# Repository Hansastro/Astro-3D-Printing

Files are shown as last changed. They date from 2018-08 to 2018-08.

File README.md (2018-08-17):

# Some 3D Objects to print for Astronomy

Now the 3D printing is become more and more popular. It is possible to create the objects we need.

The models availables are:
- [Polar finder adapter](./Polar_finder_adapter/README.md) for Canon 90° finder.
- [Finder support](./EOS1200D_Finder_Support/README.md) for a EOS 1200D

All models are under Creative Common Licence (BY-NC-SA)



The STL files are accessible per link. If you want the source files to make some modifications, they are available in the repository. You have just to clone it.

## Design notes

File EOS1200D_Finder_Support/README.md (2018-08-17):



# EOS 1200D Finder Support
Taking some photos of the night sky with a reflex camera only is not easy. The finder is two dark and the livevew allow to see only the really bright stars.

With a short focal it is possible to adjust the orientation but when we want to use a longer one, it become hard to find the object we want.

You will find here an adapter to mount a finder on a EOS 1200D.
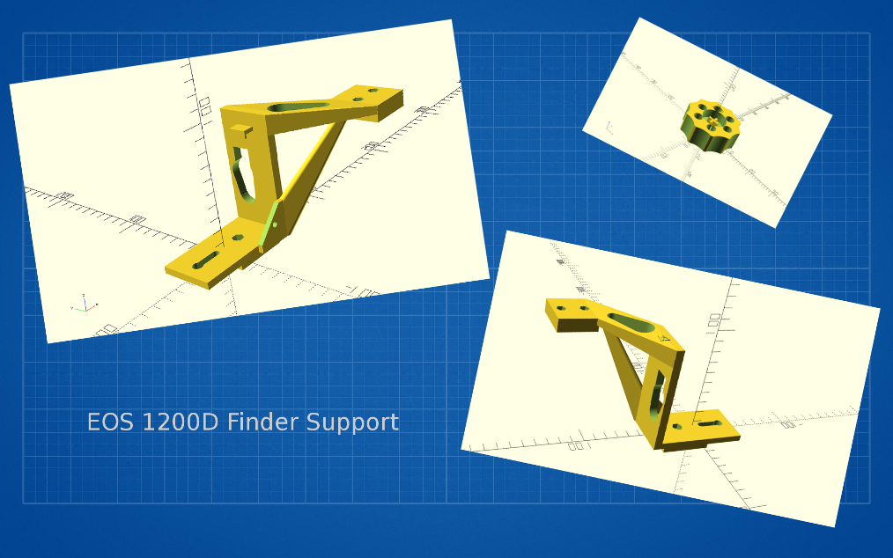
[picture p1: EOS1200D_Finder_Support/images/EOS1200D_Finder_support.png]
EOS1200D Finder support image


Why on the side? 
The finder is placed on the side, because this position is more confortable if we have a 90° finder. With the finder on the flash place, the screen of the camera will be very low. (The EOS 1200 have a fix screen)

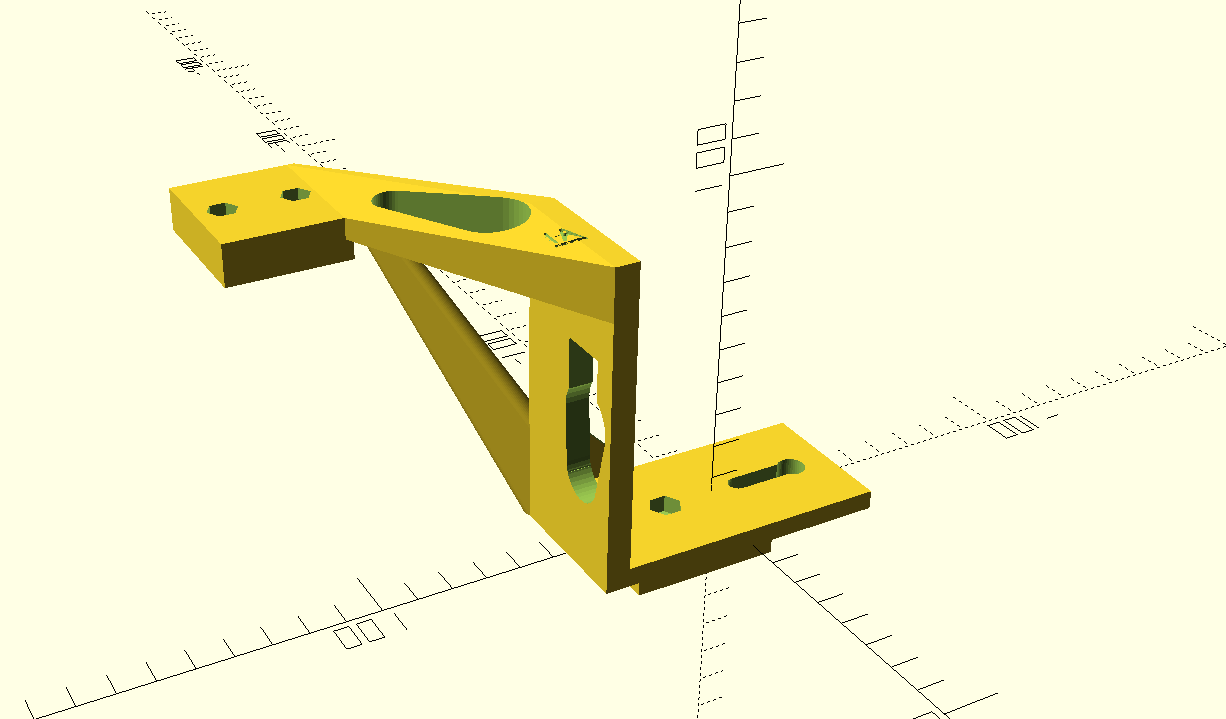
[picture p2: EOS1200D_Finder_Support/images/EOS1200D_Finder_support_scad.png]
EOS1200D Finder support image 1

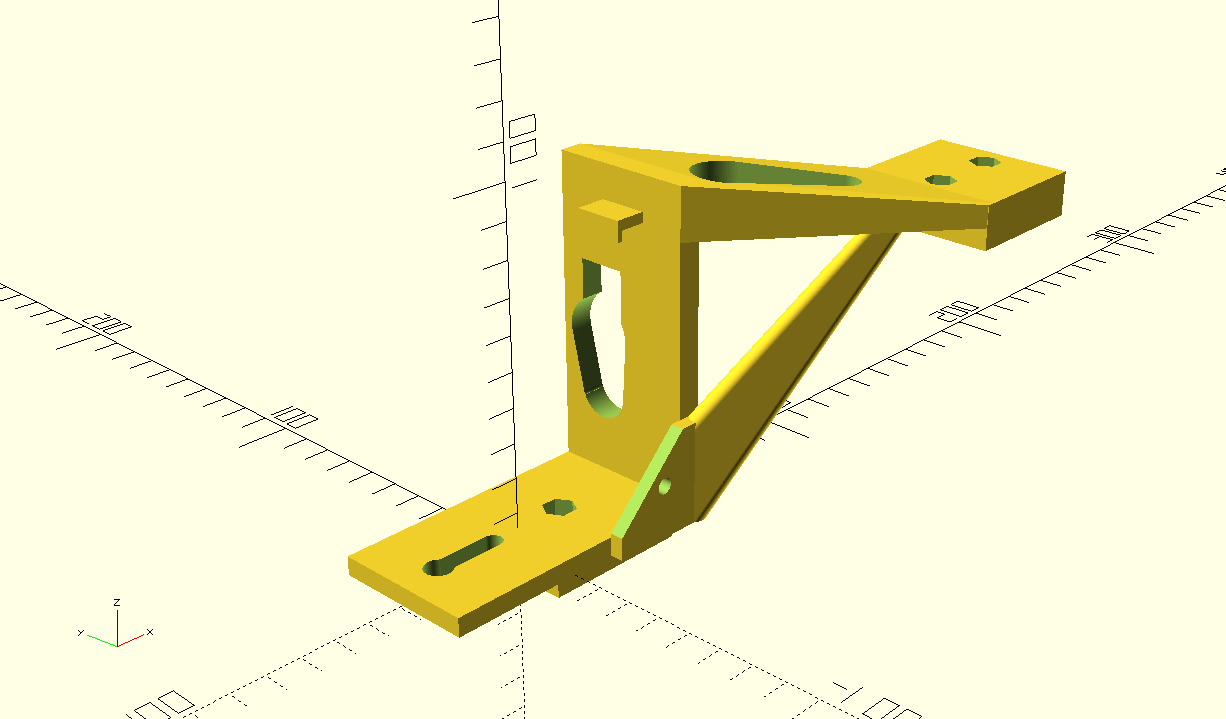
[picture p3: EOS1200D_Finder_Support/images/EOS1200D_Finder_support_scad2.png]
EOS1200D Finder support image 2


The shape is quite complex and to print it some support are required:
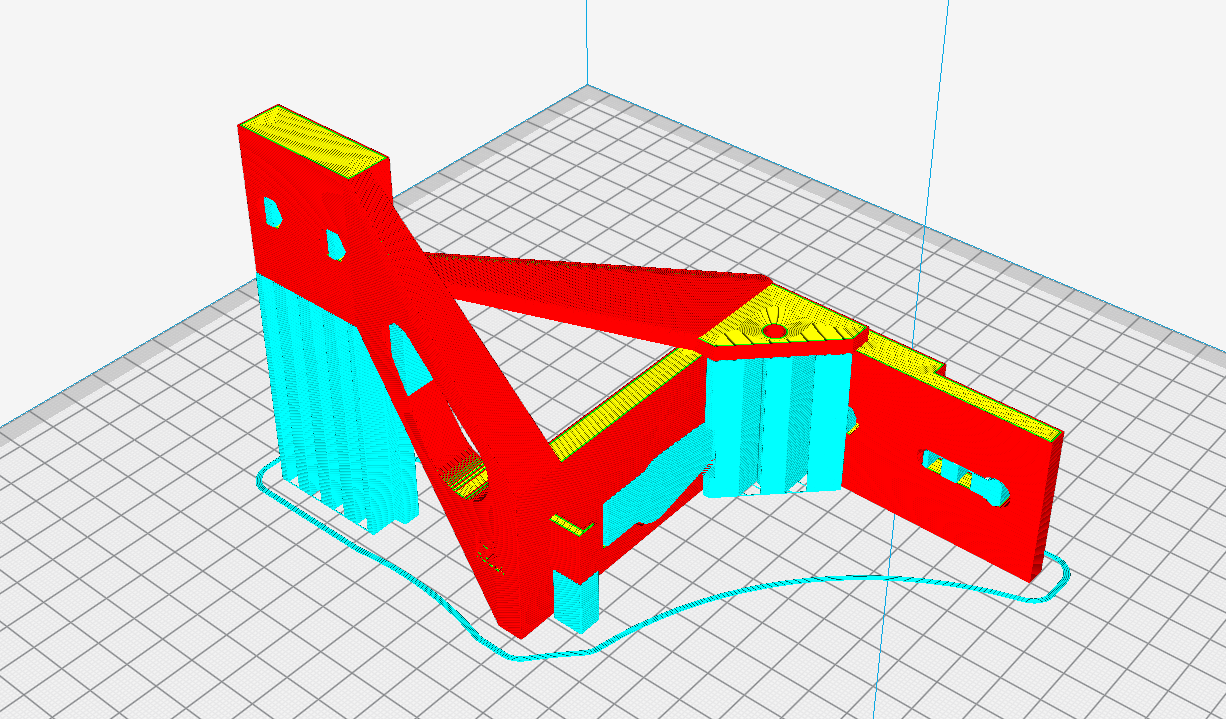
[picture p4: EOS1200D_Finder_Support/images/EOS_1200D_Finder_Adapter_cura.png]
Printing of the support


The STL files are available here:
- [EOS1200D_Finder_Support.stl](EOS1200D_Finder_Support.stl)
- [ScrewHead.stl](ScrewHead.stl) (optional)

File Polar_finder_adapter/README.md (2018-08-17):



# Polar finder adapter

The purpose of this adapter is to mount a canon 90° finder to a polar finder. The ajustement of the mount is very easier, particularly for the people who live quite in north.

Two adapters are provided:
- one for canon 90° finder to a ioptron skytracker polar finder.
- one for canon 90° finder to a Skywatcher EQ6 mount polar finder

The diameter is the same just the length changes.

Those adapters are usable on other polar finder of similar diameter.

The short version (works well for Ioptron skytracker)
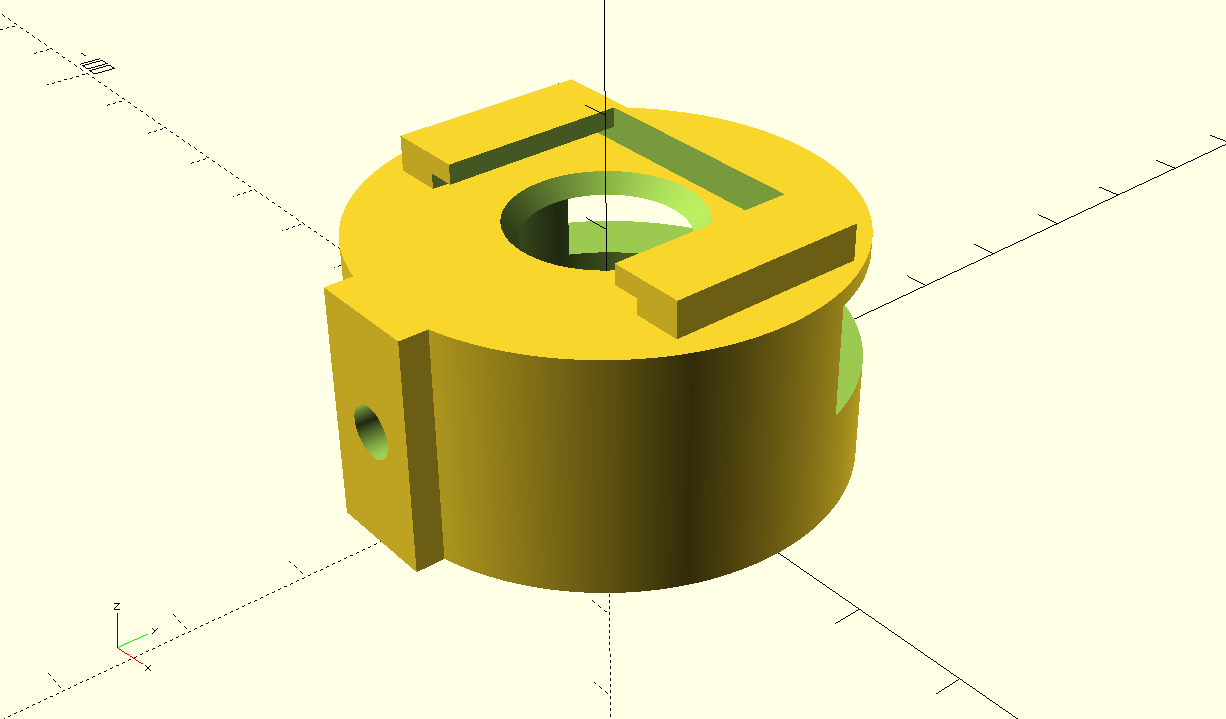
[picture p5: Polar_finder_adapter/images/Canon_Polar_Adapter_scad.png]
Canon adapter short version


The long one (works for Skywatcher EQ6 and all mount with equivalent polar finder)
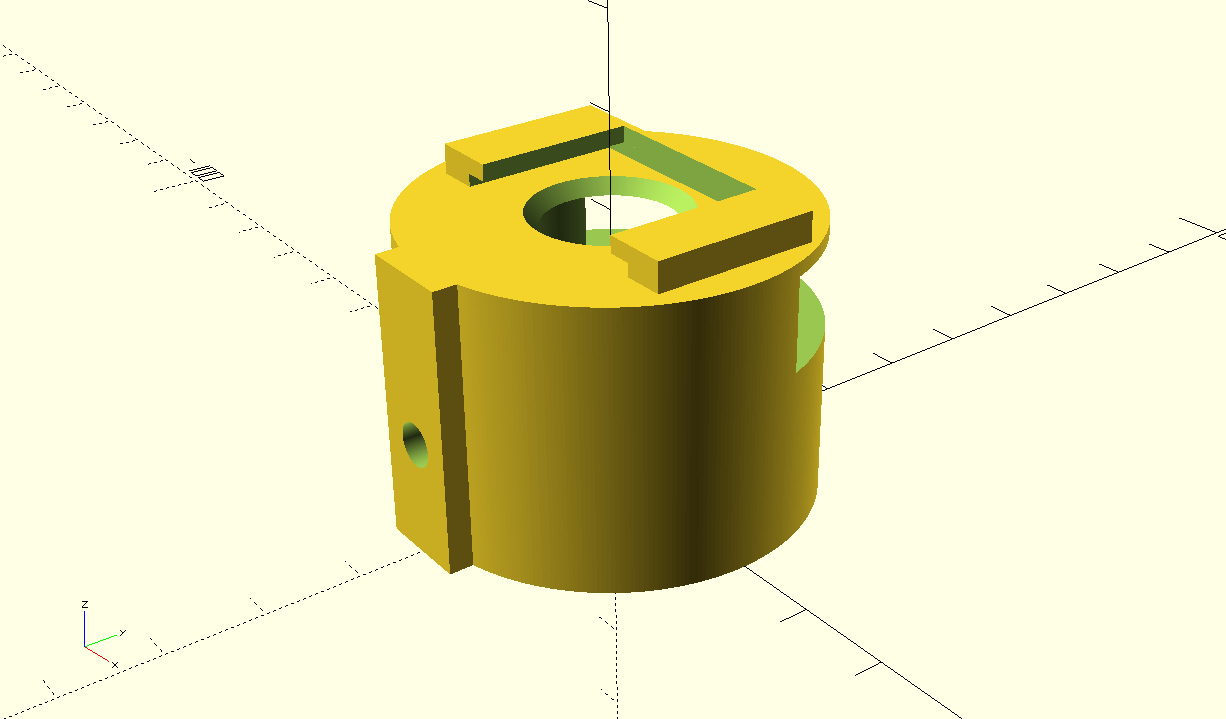
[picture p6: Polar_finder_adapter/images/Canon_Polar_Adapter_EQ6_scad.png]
Canon adapter long version


The srew to secure the adapter on the finder is a M5 in plastic. (You have to thread the hole). For a more confortable usage, a cover for the head of the screw is available:
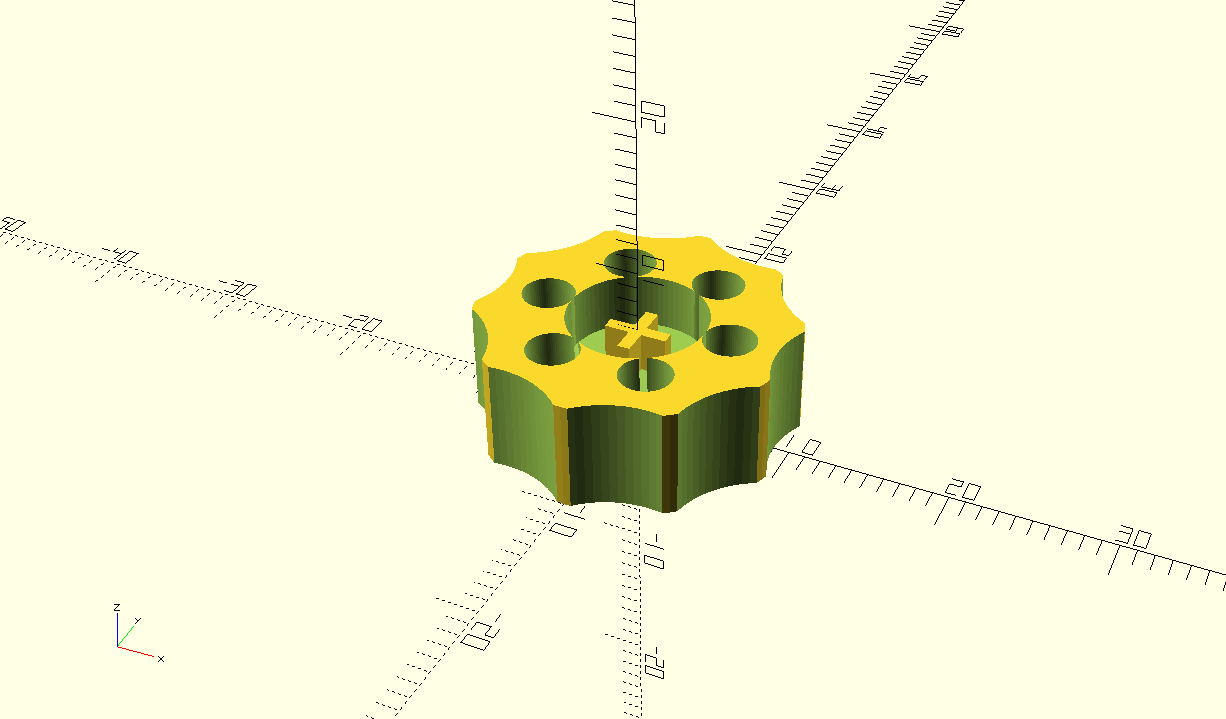
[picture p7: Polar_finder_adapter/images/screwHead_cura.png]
Screw head


To print the adapter it is recomended to orient it horizontaly. Like that:
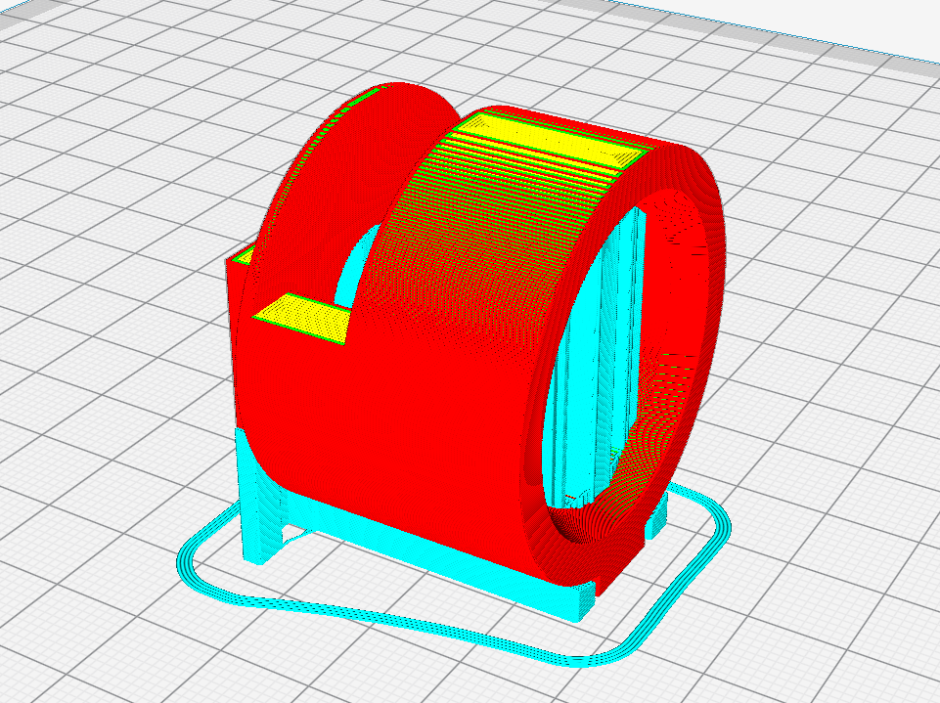
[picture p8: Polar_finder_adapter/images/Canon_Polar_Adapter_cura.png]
printing view


This avoid to fill the notch with some support material which is quite hard to remove.

The STL files are available here:
- [Canon_Polar_Adapter.stl](Canon_Polar_Adapter.stl) (Short version)
- [Canon_Polar_Adapter_EQ6.stl](Canon_Polar_Adapter_EQ6.stl) (long version)
- [ScrewHead.stl](ScrewHead.stl) (The screw cover)

All was designed in Openscad. The Openscad files are available on this repository.

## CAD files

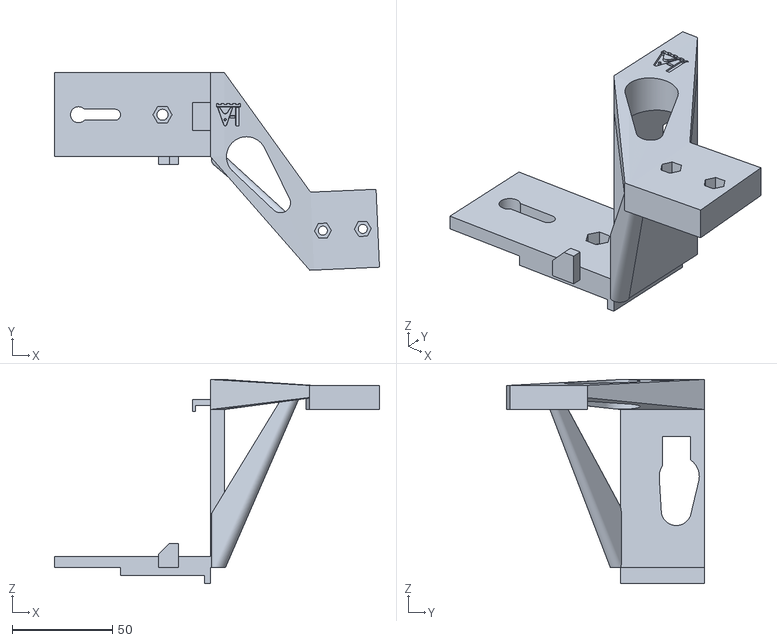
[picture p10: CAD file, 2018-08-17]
EOS1200D_Finder_Support/EOS1200D_Finder_Support.stl
162.5 x 98.8 x 102.0

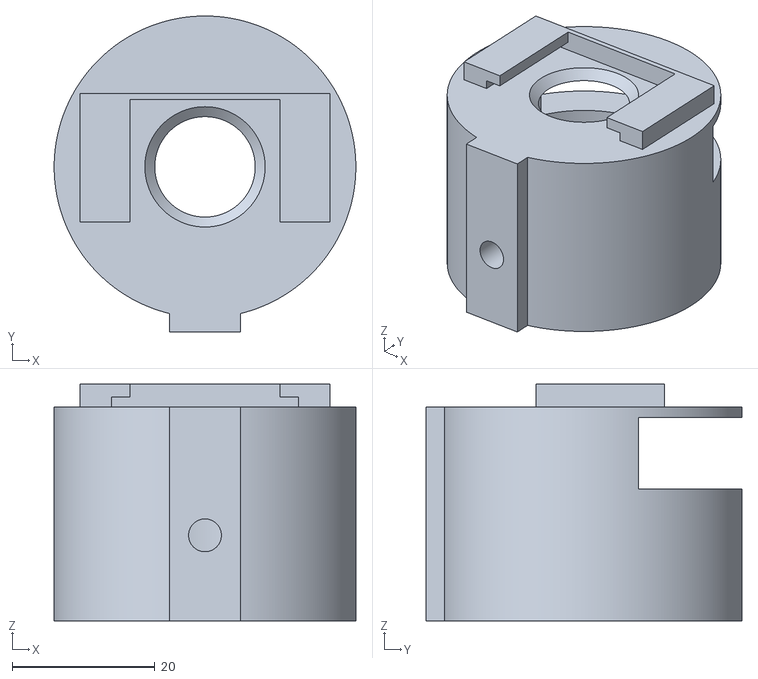
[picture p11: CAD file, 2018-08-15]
Polar_finder_adapter/Canon_Polar_Adapter_EQ6.stl
42.3 x 44.3 x 33.2

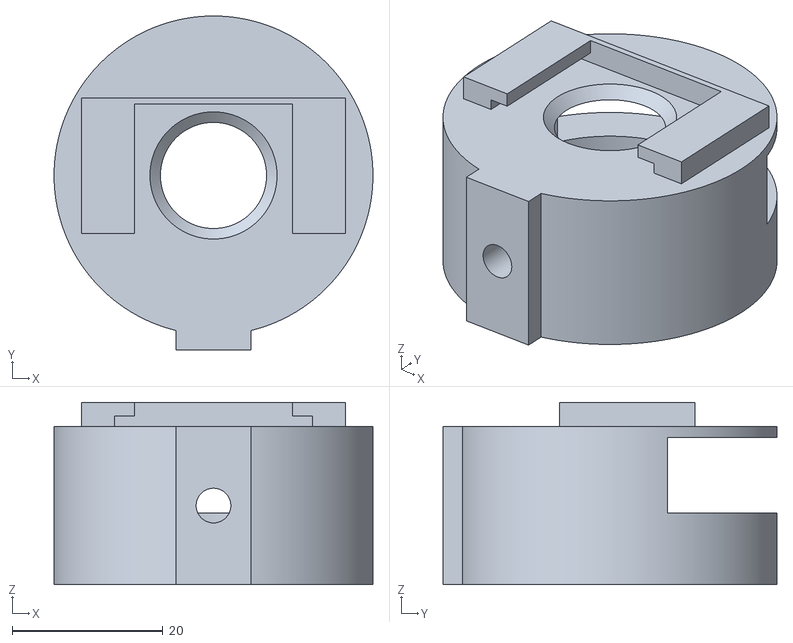
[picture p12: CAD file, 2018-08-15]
Polar_finder_adapter/Canon_Polar_Adapter.stl
42.3 x 44.3 x 24.2

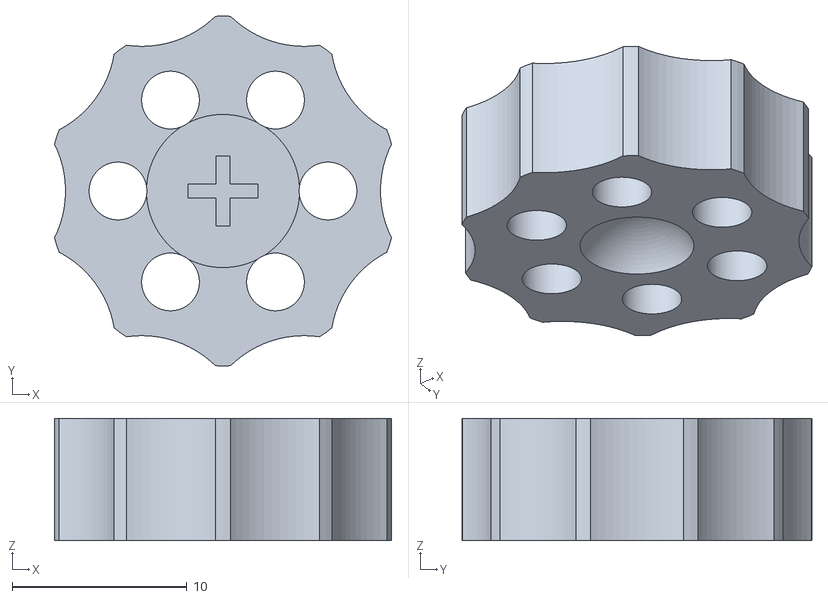
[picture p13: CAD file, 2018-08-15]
stl/ScrewHead.stl
19.3 x 20.0 x 7.00

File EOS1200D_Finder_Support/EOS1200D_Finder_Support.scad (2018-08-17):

$fn = 150;

basePlateLength = 78;
basePlateWidth = 42;
basePlateThick = 5.5;

verticalPlateHeight = 94;
verticalPlateThick = 7;

supportPlateLength = 39;
supportPlateWidth = 35;
supportPlateThick = 12;
supportPlateOffetX = 50;
supportPlateOffsetY = -20;
supportPlateRotation = 2.5;

ScrewDistance = 20;

fingerHeight =89;
fingerLength = 8.5;
fingerThick = 3;
fingerTeeth = fingerThick + 3;

module photoScrewHole(length, height, bigDiameter, smallDiameter)
{
    union()
    {
        hull()
        {
            cylinder(h=height, d=smallDiameter);
            translate([length - (bigDiameter/2 + smallDiameter/ 2), 0, 0])
            cylinder(h=height, d=smallDiameter);
        }
    translate([0,0,0])
    cylinder(h=height, d=bigDiameter);
    }
}

module base()
{
    union()
    {
        // Base Plate
        difference()
        {
            union()
            {
                translate([-basePlateLength/2, -basePlateWidth/2, 0])
                cube([basePlateLength, basePlateWidth, basePlateThick]);
                
                translate([-42/2 + 15,-42/2,-4])
                cube([42,42,4]);
                
                translate([42/2 + 15,-42/2, -4 -4])
                cube([3,42,8]);
                
                // Blocking hole
                difference()
                {
                    translate([basePlateLength/2-20 - supportPlateThick+6,
                            -basePlateWidth/2 - 4,
                            0])
                    cube([10, 4, 12]);
                    
                    translate([-10,-basePlateWidth/2 - 6,26])
                    rotate([0,45,0])
                    cube([30, 10, 60]);
                }
            }
            // Hole for the photo screw
            translate([-basePlateLength/2 + 12, 0, -1])
            photoScrewHole(length=25, height=20, bigDiameter=8, smallDiameter=5.5);
            
            // hole for photo plate screw
            translate([15, 0, 0])
            union()
            {
                translate([0, 0, -20])
                cylinder(h=40, d=5.5);
                
                translate([0, 0, basePlateThick-5])
                cylinder(h=40, d=9.6, $fn=6);
            }
        
        }
        union()
        {
            difference()
            {
                translate([basePlateLength/2, -basePlateWidth/2, 0])
                cube([verticalPlateThick, basePlateWidth, verticalPlateHeight]);
                
                translate([basePlateLength/2 - 1, 0, 20 + basePlateThick])
                cube([verticalPlateThick + 2, 14, 40]);
            
                hull()
                {
                    translate([30, 7 + 1.5, basePlateThick + 30 - 10 + 20])
                    rotate([0,90,0])
                    cylinder(h=30, d=20);
                    
                    translate([30, 7, basePlateThick + 30 - 7])
                    rotate([0,90,0])
                    cylinder(h=30, d=15);
                }
            }
            // finger
            
            translate([basePlateLength/2 - 9, -8,fingerHeight - 8])
            union()
            {
                cube([fingerLength+1, 14,3]);
                translate([0,0,-fingerTeeth +3])
                cube([1.5, 14, fingerTeeth]);
            }
        }
    }
}

module support()
{
union()
    {
      rotate([0, 0, supportPlateRotation])
      translate([supportPlateOffetX + supportPlateWidth/2, supportPlateOffsetY - supportPlateLength/2, 0])
      difference()
        {
    
            
            //translate([ScrewDistance, 0, 0])
            //cylinder(h=supportPlateThick + 3, d=4);
            translate([-supportPlateWidth/2, -supportPlateLength/2, 0])
            cube([supportPlateWidth,supportPlateLength,supportPlateThick]);  
            
            // Screws
            translate([-ScrewDistance/2, 0, -1.5])
            cylinder(h=supportPlateThick + 3, d=4.5);
            translate([-ScrewDistance/2, 0, 2.5])
            cylinder(h=supportPlateThick + 3, d=8.5, $fn=6);
            
            translate([ScrewDistance/2, 0, -1.5])
            cylinder(h=supportPlateThick + 3, d=4.5);
            translate([ScrewDistance/2, 0, 2.5])
            cylinder(h=supportPlateThick + 3, d=8.5, $fn=6);
        
         }
     difference()
         {
         hull()
             {
             rotate([0, 0, supportPlateRotation])
             translate([supportPlateOffetX + supportPlateWidth/2, supportPlateOffsetY - supportPlateLength/2, 0])
             translate([-supportPlateWidth/2 + 0.1, -supportPlateLength / 2, supportPlateThick - 6])
             cube([2.1, supportPlateLength, 6]);
             
             translate([verticalPlateThick / 2 - 0.5,0,0])
             cube([verticalPlateThick, basePlateWidth, 15]);    
             }
         hull()
             {
                 translate([21,0,0])
                 cylinder(h=30, d=20);
                     
                 translate([38,-23,0])
                 cylinder(h=30, d=10);
             }
        }
     hull()
         {
             translate([supportPlateOffetX - 5, supportPlateOffsetY - supportPlateLength + 24, supportPlateThick - 6])
             cylinder(h=6, d=5);
             //cube([3,10,6]);
             translate([7,verticalPlateThick/2 - 5,-verticalPlateHeight + 15])
             cylinder(h=27, d=verticalPlateThick);
             //cube([verticalPlateThick,5,15]);
         }
    }
}

//photoScrewHole(20, 20, 10, 5);

difference()
{
    union()
    {
        base();
        translate([basePlateLength/2+ verticalPlateThick - 2 -8, -basePlateWidth/ 2, verticalPlateHeight - 15])
        support();
    }
    translate([basePlateLength/2 + 9,0,verticalPlateHeight+0.1])
    //translate([basePlateLength/2 + 65, -37.5 ,verticalPlateHeight - 8.8])
    rotate([0, 180, 180])
    scale([0.08, 0.08, 0.01])
    //cube(10,10.5);
    surface(file = "../ressources/logo_small.png", center = true, invert = false);
}

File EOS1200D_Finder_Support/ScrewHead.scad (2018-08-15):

$fn=80;

headScrewDiameter = 8.75;
headScrewDeep = 3.5;

buttonThick = 7;

module cylinderLoop(amount, radius, diameter, height)
{
    for (angle = [0 : 360 / amount: 359])
    {
        rotate(a=[0, 0, angle])
        translate([radius, 0, 0])
        union()
        {
            cylinder(h=height - diameter, d=diameter, center=true);
            translate([0, 0 ,height/2 - diameter/2])
            sphere(d=diameter, center=true);
            translate([0, 0 ,-height/2 + diameter/2])
            sphere(d=diameter, center=true);
        }
    }
}

//cylinderLoop(5, 20, 20, 40);

module negativScrew(height, screwThick, screwWidth)
{
        union()
        {
            translate([-screwWidth / 2, -screwThick / 2, -1])
            cube([screwWidth, screwThick, ,height + 2]);
            rotate([0, 0, 90])
            translate([-screwWidth / 2, -screwThick / 2, -1])
            cube([screwWidth, screwThick, ,height + 2]);
        }
}  

difference()
{
    union()
    {
        difference()
        {
            cylinder(h=buttonThick, d=20);
            translate([0,0,buttonThick - headScrewDeep])
            cylinder(h=10, d=headScrewDiameter);

        }
        translate([0,0,3])
        //rotate([180,0,0])
        union()
        {
            translate([0,0,0])
            negativScrew(height= 2, screwThick= .8, screwWidth = 4);
            //cylinder(h=2.5, d=8.8);
        }
    }
   cylinderLoop(amount=10, radius=15, diameter=12, height=40);
   translate([0,0,0]) 
   cylinderLoop(amount=6, radius=6, diameter=3.3, height=23);
   translate([0,0,-1.5])
   sphere(d=7);
}

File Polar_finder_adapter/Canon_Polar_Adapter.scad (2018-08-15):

$fn = 300;

internDiameter = 30.3;
wallThickness = 6.0;

tubeHigh = 21;
ceilingThickness = 1.5;
viewHoleDiameter = 14;

focusHoleHeight = 10;


translate([0,1.3,tubeHigh])
rotate(a=180, v=[0,0,1])
canonAdpter();

difference()
{
    difference()
    {
        difference()
        {
            union()
            {
                difference()
                {
                    cylinder(h=tubeHigh,d=internDiameter + wallThickness*2);
                    translate([0,0,-ceilingThickness])
                    union()
                    {
                        translate([0 ,0, tubeHigh - 1])
                        cylinder(h=tubeHigh/2, d=viewHoleDiameter);
                    
                        cylinder(h=tubeHigh, d=internDiameter);
                    }
                }
                translate([-5, -internDiameter/2 - wallThickness - 2, 0])
                cube(size=[10, wallThickness, tubeHigh]);
           }
           translate([0,internDiameter/2 + 4,tubeHigh - ceilingThickness - focusHoleHeight/2])
           cube(size=[internDiameter + wallThickness*2, 25, focusHoleHeight], center=true);
        }
        rotate(a=90, v=[1,0,0])
        translate([0,tubeHigh / 1/2],0)
        cylinder(h=25, d=4.6);
    }
    union()
    {
        translate([0,0,-2])
        cylinder(h=internDiameter, d1=internDiameter+wallThickness, d2=2);
        translate([0,0,tubeHigh-8])
        cylinder(h=viewHoleDiameter, d1=2, d2=viewHoleDiameter*2);
    }
}

module canonAdpter()
{
    width = 35;
    length = 18;
    height = 3.2;
    supportThickness = 1.8 ; //1.72 a little too small
    supportWidth = 2.6;
    supportDistance = 21;
    
    translate([0, 0, height/2])
    difference()
    {
    cube(size=[width, length, height], center=true);
    union()
        {
            translate([0,+1,-0.1])
            cube(size=[supportDistance, length+0.3, height+ 0.3], center=true);
            translate([0, +1, -supportThickness])
            cube(size=[supportDistance + supportWidth*2, length+0.3, height], center=true);
        }
    }
}

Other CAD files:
EOS1200D_Finder_Support/ScrewHead.stl
Polar_finder_adapter/Canon_Polar_Adapter_EQ6.scad

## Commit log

2018-08-15 Add the canon polar adapter
    [Canon_Adpater_Polar.stl, Canon_Polar_Adapter.scad, Canon_Polar_Adapter.stl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]
2018-08-15 Add the EOS1200 finder support
    [EOS1200D_Finder_Support.scad, EOS1200D_Finder_Support.stl, ScrewHead.scad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]
2018-08-15 change the rigth of the files
    [Canon_Polar_Adapter.scad, Canon_Polar_Adapter_EQ6.scad, ScrewHead.scad]
2018-08-17 Improve the support
    [EOS1200D_Finder_Support.scad, EOS1200D_Finder_Support.stl]
